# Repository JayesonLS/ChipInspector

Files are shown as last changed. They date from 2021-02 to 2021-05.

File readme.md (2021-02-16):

Circuits for Arbitrary Inspection/Operation of Integrated Circuits
==================================================================

ChipInspector24
---------------

Circuit that made use of the many 5v pins on a Teensy++. Never 
tested as the need came about for a 50 pin device.

ChipInspector40
---------------

Circuit using an inexpensive Arduino Pro Micro and many input
and output shift registers. Very incomplete.

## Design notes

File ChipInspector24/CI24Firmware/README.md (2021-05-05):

Chip Inspector 24 Firmware
==========================

The firmware is built and programmed with 
[Teensyduino](https://www.pjrc.com/teensy/td_download.html).

Teensyduino version 1.53
Arduino version 1.8.13

Operation
---------

To operate the Chip Inspector 24, connect the Teensy to 
computer, then run a serial terminal to communicate with
the board. The serial terminal in the Arduino environment
may be used. 

Chip Inspector 23 is controlled with the following commands
from the serial terminal.

**`logicdump <device pin count>`**

For example, `logicdump 20`. 

This command will attempt to apply every possible combination
of inputs to every non-power pin of the inserted device. Inputs 
are driven through a 10K resistor. For every combination of inputs,
the levels on the device pins are read back. Every combination 
attempted inputs and actual pin values are then output to the 
serial terminal.

Before the logic dump begins, the device is powered up and a
current test is applied. The test will be halted if excessive
current consumption is detected.

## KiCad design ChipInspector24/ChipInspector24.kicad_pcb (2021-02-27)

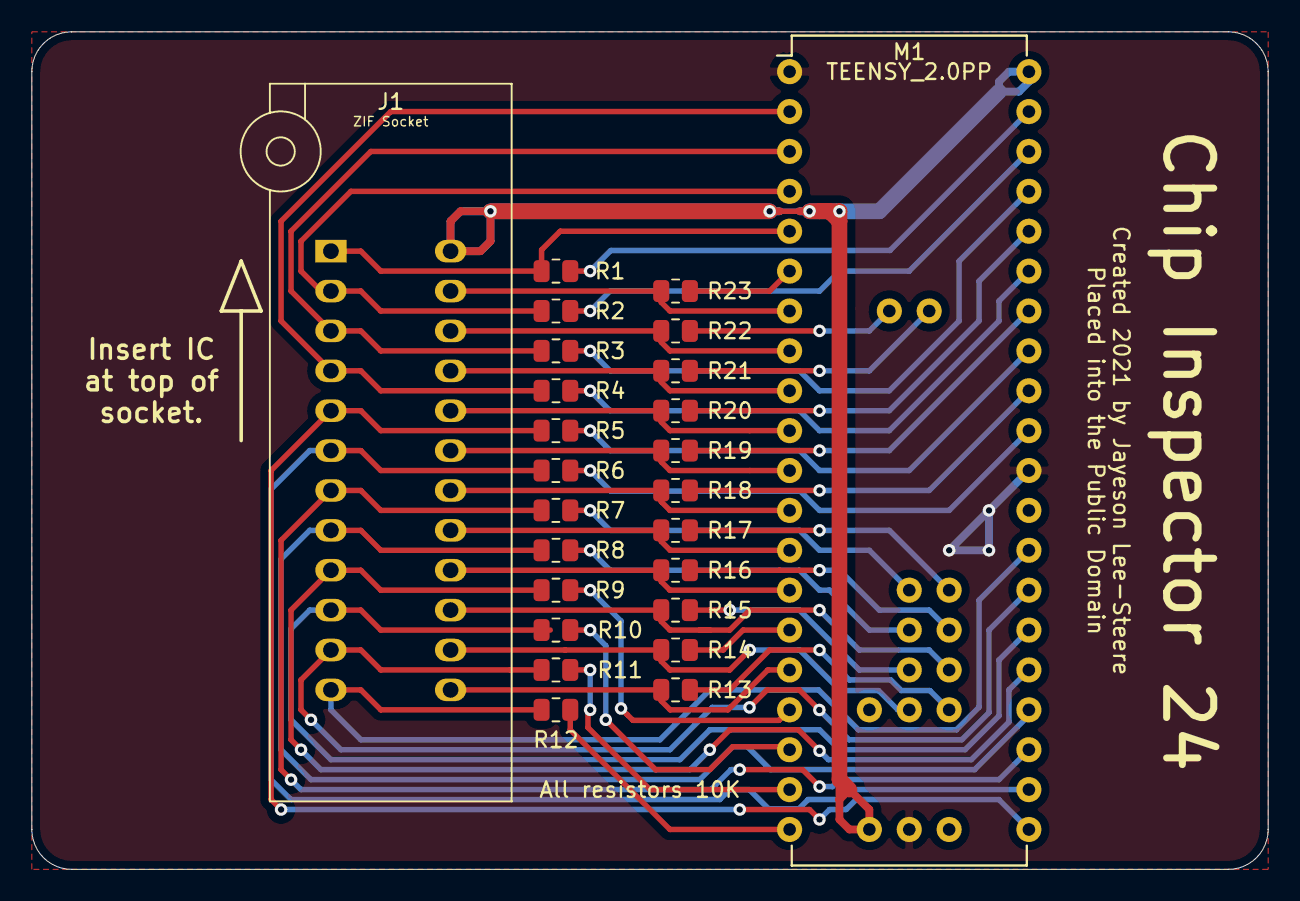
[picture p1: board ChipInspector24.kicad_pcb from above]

Board: 2 copper layers, 78.7 x 53.3 mm, 25 parts (0 on the bottom side), 48 nets.

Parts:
J1: ZIF Socket; DIP_Socket-24_W4.3_W5.08_W7.62_W10.16_W10.9_3M_224-5248-00-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
M1: TEENSY_2.0PP; Teensy_2.0PP
R1, R2, R3, R4, R5, R6, R7, R8, R9, R10, R11, R12, R13, R14, R15, R16, R17, R18, R19, R20, R21, R22, R23: 10K; R_0805_2012Metric

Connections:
GND: M1.1, M1.30, M1.42
P01: J1.1, M1.5, R1.1
P01R: M1.39, R1.2
P02: J1.2, M1.4, R2.1
P02R: M1.38, R2.2
P03: J1.3, M1.3, R3.1
P03R: M1.37, R3.2
P04: J1.4, M1.2, R4.1
P04R: M1.35, R4.2
P05: J1.5, M1.21, R5.1
P05R: M1.33, R5.2
P06: J1.6, M1.22, R6.1
P06R: M1.31, R6.2
P07: J1.7, M1.23, R7.1
P07R: M1.45, R7.2
P08: J1.8, M1.24, R8.1
P08R: M1.46, R8.2
P09: J1.9, M1.25, R9.1
P09R: M1.17, R9.2
P10: J1.10, M1.26, R10.1
P10R: M1.18, R10.2
P11: J1.11, M1.27, R11.1
P11R: M1.19, R11.2
P12: J1.12, M1.28, R12.1
P12R: M1.20, R12.2
P13: J1.13, M1.16, R13.1
P13R: M1.49, R13.2
P14: J1.14, M1.48, R14.1
P14R: M1.15, R14.2
P15: J1.15, M1.50, R15.1
P15R: M1.47, R15.2
P16: J1.16, M1.14, R16.1
P16R: M1.51, R16.2
P17: J1.17, M1.13, R17.1
P17R: M1.52, R17.2
P18: J1.18, M1.12, R18.1
P18R: M1.32, R18.2
P19: J1.19, M1.11, R19.1
P19R: M1.34, R19.2
P20: J1.20, M1.10, R20.1
P20R: M1.36, R20.2
P21: J1.21, M1.9, R21.1
P21R: M1.53, R21.2
P22: J1.22, M1.8, R22.1
P22R: M1.54, R22.2
P23: J1.23, M1.7, R23.1
P23R: M1.6, R23.2
VCC: J1.24, M1.40, M1.41

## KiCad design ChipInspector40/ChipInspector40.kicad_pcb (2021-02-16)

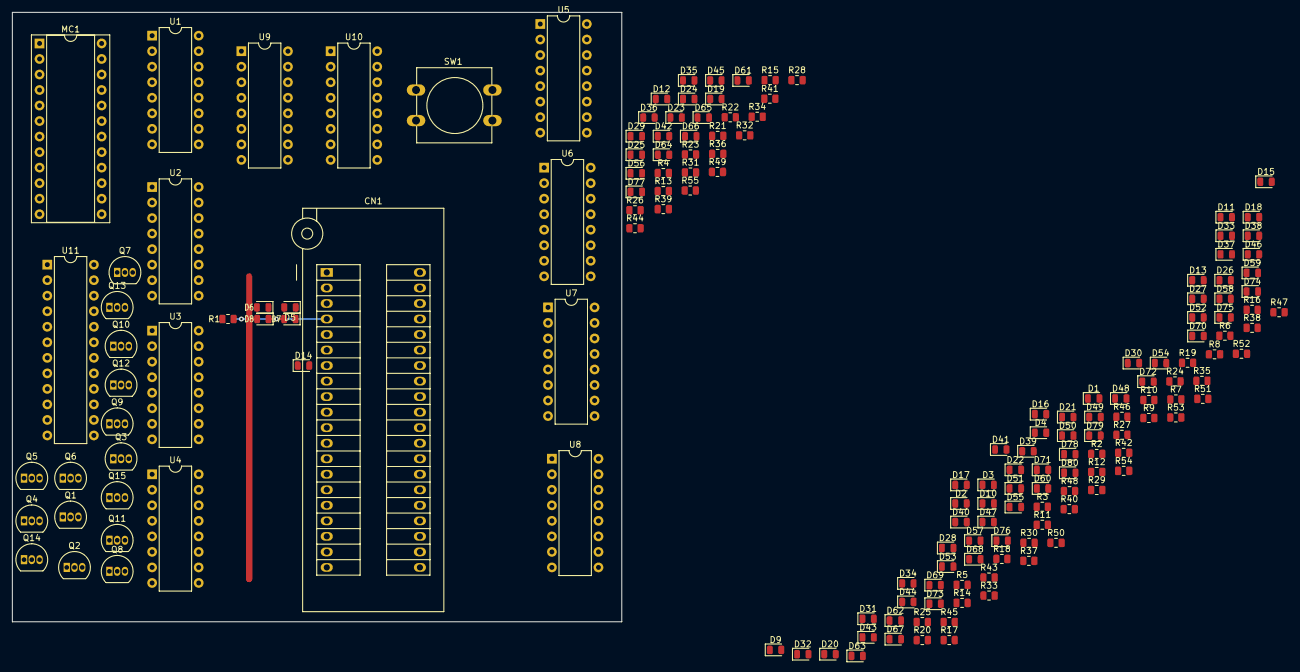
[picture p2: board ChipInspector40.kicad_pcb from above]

Board: 2 copper layers, 99.7 x 99.7 mm, 164 parts (0 on the bottom side), 120 nets.

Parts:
CN1: 40 Pin ZIF; 3M_Textool_240-1288-00-0602J_2x20_P2.54mm
D1, D2, D3, D4, D5, D6, D7, D8, D9, D10, D11, D12, D13, D14, D15, D16, D17, D18, D19, D20, D21, D22, D23, D24, D25, D26, D27, D28, D29, D30, D31, D32, D33, D34, D35, D36, D37, D38, D39, D40, D41, D42, D43, D44, D45, D46, D47, D48, D49, D50, D51, D52, D53, D54, D55, D56, D57, D58, D59, D60, D61, D62, D63, D64, D65, D66, D67, D68, D69, D70, D71, D72, D73, D74, D75, D76, D77, D78, D79, D80: 1N4148; D_0805_2012Metric
MC1: ARDUINO_PRO_MICRO; DIP-24_W10.16mm_Socket
Q1, Q2, Q3, Q4, Q5, Q6, Q7, Q8, Q9, Q10, Q11, Q12, Q13, Q14, Q15: PN2222A; TO-92_Inline
R1, R2, R3, R4, R5, R6, R7, R8, R9, R10, R11, R12, R13, R14, R15, R16, R17, R18, R19, R20, R21, R22, R23, R24, R25, R26, R27, R28, R29, R30, R31, R32, R33, R34, R35, R36, R37, R38, R39, R40: 10K; R_0805_2012Metric
R41, R42, R43, R44, R45, R46, R47, R48, R49, R50, R51, R52, R53, R54, R55: 1K; R_0805_2012Metric
SW1: Reset; SW_PUSH-12mm
U1, U2, U3, U4, U5: 74LS/HC165; DIP-16_W7.62mm
U6, U7, U8, U9, U10: 74LS/HC595; DIP-16_W7.62mm
U11: 74LS154; DIP-24_W7.62mm

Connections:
/PIN1: CN1.1, D1.2, D2.1, R1.2, U1.11
/PIN1_DRIVE: R1.1, U6.15
/PIN2: CN1.2, D3.2, D4.1, R2.2, U1.12
/PIN2_DRIVE: R2.1, U6.1
/PIN2_READ: Q1.3, Q2.3
/PIN3: CN1.3, D5.2, D6.1, R3.2, U1.13
/PIN3_DRIVE: R3.1, U6.2
/PIN4: CN1.4, D7.2, D8.1, R4.2, U1.14
/PIN4_DRIVE: R4.1, U6.3
/PIN5: CN1.5, D9.2, D10.1, R5.2, U1.3
/PIN5_DRIVE: R5.1, U6.4
/PIN6: CN1.6, D11.2, D12.1, R6.2, U1.4
/PIN6_DRIVE: R6.1, U6.5
/PIN7: CN1.7, D13.2, D14.1, R7.2, U1.5
/PIN7_DRIVE: R7.1, U6.6
/PIN8: CN1.8, D15.2, D16.1, R8.2, U1.6
/PIN8_DRIVE: R8.1, U6.7
/PIN9: CN1.9, D17.2, D18.1, R9.2, U2.11
/PIN9_DRIVE: R9.1, U7.15
/PIN10: CN1.10, D19.2, D20.1, R10.2, U2.12
/PIN10_DRIVE: R10.1, U7.1
/PIN11: CN1.11, D21.2, D22.1, R11.2, U2.13
/PIN11_DRIVE: R11.1, U7.2
/PIN12: CN1.12, D23.2, D24.1, R12.2, U2.14
/PIN12_DRIVE: R12.1, U7.3
/PIN13: CN1.13, D25.2, D26.1, R13.2, U2.3
/PIN13_DRIVE: R13.1, U7.4
/PIN14: CN1.14, D27.2, D28.1, R14.2, U2.4
/PIN14_DRIVE: R14.1, U7.5
/PIN15: CN1.15, D29.2, D30.1, R15.2, U2.5
/PIN15_DRIVE: R15.1, U7.6
/PIN16: CN1.16, D31.2, D32.1, R16.2, U2.6
/PIN16_DRIVE: R16.1, U7.7
/PIN17: CN1.17, D33.2, D34.1, R17.2, U3.11
/PIN17_DRIVE: R17.1, U8.15
/PIN18: CN1.18, D35.2, D36.1, R18.2, U3.12
/PIN18_DRIVE: R18.1, U8.1
/PIN19: CN1.19, D37.2, D38.1, R19.2, U3.13
/PIN19_DRIVE: R19.1, U8.2
/PIN20: CN1.20, D39.2, D40.1, R20.2, U3.14
/PIN20_DRIVE: R20.1, U8.3
/PIN21: CN1.21, D41.2, D42.1, R40.2, U3.3
/PIN21_DRIVE: R40.1, U8.4
/PIN22: CN1.22, D43.2, D44.1, R39.2, U3.4
/PIN22_DRIVE: R39.1, U8.5
/PIN23: CN1.23, D45.2, D46.1, R38.2, U3.5
/PIN23_DRIVE: R38.1, U8.6
/PIN24: CN1.24, D47.2, D48.1, R37.2, U3.6
/PIN24_DRIVE: R37.1, U8.7
/PIN25: CN1.25, D49.2, D50.1, R36.2, U4.11
/PIN25_DRIVE: R36.1, U9.15
/PIN26: CN1.26, D51.2, D52.1, R35.2, U4.12
/PIN26_DRIVE: R35.1, U9.1
/PIN27: CN1.27, D53.2, D54.1, R34.2, U4.13
/PIN27_DRIVE: R34.1, U9.2
/PIN28: CN1.28, D55.2, D56.1, R33.2, U4.14
/PIN28_DRIVE: R33.1, U9.3
/PIN29: CN1.29, D57.2, D58.1, R32.2, U4.3
/PIN29_DRIVE: R32.1, U9.4
/PIN30: CN1.30, D59.2, D60.1, R31.2, U4.4
/PIN30_DRIVE: R31.1, U9.5
/PIN31: CN1.31, D61.2, D62.1, R30.2, U4.5
/PIN31_DRIVE: R30.1, U9.6
/PIN32: CN1.32, D63.2, D64.1, R29.2, U4.6
/PIN32_DRIVE: R29.1, U9.7
/PIN33: CN1.33, D65.2, D66.1, R28.2, U5.11
/PIN33_DRIVE: R28.1, U10.15
/PIN34: CN1.34, D67.2, D68.1, R27.2, U5.12
/PIN34_DRIVE: R27.1, U10.1
/PIN35: CN1.35, D69.2, D70.1, R26.2, U5.13
/PIN35_DRIVE: R26.1, U10.2
/PIN36: CN1.36, D71.2, D72.1, R25.2, U5.14
/PIN36_DRIVE: R25.1, U10.3
/PIN37: CN1.37, D73.2, D74.1, R24.2, U5.3
/PIN37_DRIVE: R24.1, U10.4
/PIN38: CN1.38, D75.2, D76.1, R23.2, U5.4
/PIN38_DRIVE: R23.1, U10.5
/PIN39: CN1.39, D77.2, D78.1, R22.2, U5.5
/PIN39_DRIVE: R22.1, U10.6
/PIN40: CN1.40, D79.2, D80.1, R21.2, U5.6
/PIN40_DRIVE: R21.1, U10.7
GND: D2.2, D4.2, D6.2, D8.2, D10.2, D12.2, D14.2, D16.2, D18.2, D20.2, D22.2, D24.2, D26.2, D28.2, D30.2, D32.2, D34.2, D36.2, D38.2, D40.2, D42.2, D44.2, D46.2, D48.2, D50.2, D52.2, D54.2, D56.2, D58.2, D60.2, D62.2, D64.2, D66.2, D68.2, D70.2, D72.2, D74.2, D76.2, D78.2, D80.2, MC1.3, MC1.4, Q1.1, Q2.1, Q3.1, Q4.1, Q5.1, Q6.1, Q7.1, Q8.1, Q9.1, Q10.1, Q11.1, Q12.1, Q13.1, Q14.1, Q15.1, SW1.2, U1.8, U1.10, U1.15, U2.8, U2.15, U3.8, U3.15, U4.8, U4.15, U5.8, U5.15, U6.8, U7.8, U8.8, U9.8, U10.8, U11.12, U11.18, U11.19
unnamed: MC1.22, SW1.1
unnamed: Q1.2, R41.1
unnamed: Q2.2, R42.1
unnamed: Q3.2, R43.1
unnamed: Q4.2, R44.1
unnamed: Q5.2, R45.1
unnamed: Q6.2, R46.1
unnamed: Q7.2, R47.1
unnamed: Q8.2, R48.1
unnamed: Q9.2, R49.1
unnamed: Q10.2, R50.1
unnamed: Q11.2, R51.1
unnamed: Q12.2, R52.1
unnamed: Q13.2, R53.1
unnamed: Q14.2, R54.1
unnamed: Q15.2, R55.1
unnamed: R41.2, U11.2
unnamed: R42.2, U11.3
unnamed: R43.2, U11.4
unnamed: R44.2, U11.5
unnamed: R45.2, U11.6
unnamed: R46.2, U11.7
unnamed: R47.2, U11.8
unnamed: R48.2, U11.9
unnamed: R49.2, U11.10
unnamed: R50.2, U11.11
unnamed: R51.2, U11.13
unnamed: R52.2, U11.14
unnamed: R53.2, U11.15
unnamed: R54.2, U11.16
unnamed: R55.2, U11.17
unnamed: U1.1, U2.1, U3.1, U4.1, U5.1
unnamed: U1.2, U2.2, U3.2, U4.2, U5.2
unnamed: U1.9, U2.10
unnamed: U2.9, U3.10
unnamed: U3.9, U4.10
unnamed: U4.9, U5.10
VCC: D1.1, D3.1, D5.1, D7.1, D9.1, D11.1, D13.1, D15.1, D17.1, D19.1, D21.1, D23.1, D25.1, D27.1, D29.1, D31.1, D33.1, D35.1, D37.1, D39.1, D41.1, D43.1, D45.1, D47.1, D49.1, D51.1, D53.1, D55.1, D57.1, D59.1, D61.1, D63.1, D65.1, D67.1, D69.1, D71.1, D73.1, D75.1, D77.1, D79.1, MC1.21, U1.16, U2.16, U3.16, U4.16, U5.16, U6.16, U7.16, U8.16, U9.16, U10.16, U11.24

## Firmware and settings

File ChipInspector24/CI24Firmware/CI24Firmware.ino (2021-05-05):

/* 
Chip Inspector 24 Firmware
Copyright (C) 2021 Titanium Studios Pty. Ltd.

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
You should have received a copy of the GNU General Public License
along with this program.  If not, see <http://www.gnu.org/licenses/>.
*/

#include "LogicDump.h"
#include "PinControl.h"

const char* HELP_COMMAND = "help";
const char* LOGICDUMP_COMMAND = "logicdump";

const char* LOGICDUMP_SUPPORTED_PIN_COUNTS_TEXT = "10, 12, 14, 16, 18, 20, 22 or 24";

// the setup routine runs once when you press reset:
void setup()
{
  Serial.begin(9600); // USB is always 12 Mbit/sec

  DebugCheckSocketPins();
}

String ReadCommandString()
{
  String result;

  for (;;)
  {
    while (Serial.available())
    {
      int data = Serial.read();
      if (data == '\n')
      {
        return result;
      }
      else if (data >= 0)
      {
        result += (char)data;
      }
    }
  }
}

void ShowHelp()
{
    Serial.println("Supported commands:");
    Serial.println();

    Serial.print(HELP_COMMAND);
    Serial.println(" - Show this help");
    Serial.println();
    
    Serial.print(LOGICDUMP_COMMAND);
    Serial.println(" <pin count> - Dump I/O logic tables for device.");
    Serial.print("<pin count> is one of ");
    Serial.println(LOGICDUMP_SUPPORTED_PIN_COUNTS_TEXT);
    Serial.print("For example: ");
    Serial.print(LOGICDUMP_COMMAND);
    Serial.println(" 24");
    Serial.println();
}

bool IsSupportedDevicePinCount(int pinCount)
{
  return pinCount >= 10 && pinCount <= 24 && (pinCount % 0x01) == 0;
}

// the loop routine runs over and over again forever:
void loop()
{
  // Initialize Teensy.
  delay(100);  // Just in case a previous operation needs time to settle.
  //TODO: Set all pins to inputs.

  // Show welcome message. 
  Serial.print("Enter command string. Enter '");
  Serial.print(HELP_COMMAND);
  Serial.println("' for list of commands.");
  
  String commandString = ReadCommandString().trim().toLowerCase();
  if (commandString.length() > 0)
  {   
    Serial.print("Received command string: ");
    Serial.println(commandString);

    if (commandString == HELP_COMMAND)
    {
      ShowHelp();
    }
    else if (commandString.startsWith(LOGICDUMP_COMMAND))
    {
      int pinCount = 0;

      if (sscanf(commandString.c_str() + strlen(LOGICDUMP_COMMAND), "%d", &pinCount) != 1 ||
          !IsSupportedDevicePinCount(pinCount))
      {
        Serial.print("Please specify one of the supported pin counts: ");
        Serial.println(LOGICDUMP_SUPPORTED_PIN_COUNTS_TEXT);
      }
      else
      {
        LogicDump(pinCount);
      }
    }
    else
    {
        Serial.println("Unrecognised command.");
    }
  }
}

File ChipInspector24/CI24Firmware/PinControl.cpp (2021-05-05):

/* 
Chip Inspector 24 Firmware
Copyright (C) 2021 Titanium Studios Pty. Ltd.

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
You should have received a copy of the GNU General Public License
along with this program.  If not, see <http://www.gnu.org/licenses/>.
*/

#include <Arduino.h>
#include "PinControl.h"

#define MAX_PINS 24
#define MAX_IO_PINS 22

static uint8_t socketDirectPins[MAX_PINS] =
{
  2, // 1
  1, // 2
  0, // 3
  27, // 4
  45, // 5
  44, // 6
  43, // 7
  42, // 8
  41, // 9
  40, // 10
  39, // 11
  38, // 12
  13, // 13
  35, // 14
  30, // 15
  11, // 16
  10, // 17
  9, // 18
  8, // 19
  7, // 20
  6, // 21
  5, // 22
  4, // 23
  (uint8_t)-1  // 24
};

static uint8_t socketResistorPins[MAX_PINS] =
{
  26, // 1
  37, // 2
  24, // 3
  22, // 4
  20, // 5
  18, // 6
  32, // 7
  33, // 8
  14, // 9
  15, // 10
  16, // 11
  17, // 12
  31, // 13
  12, // 14
  34, // 15
  29, // 16
  28, // 17
  19, // 18
  21, // 19
  23, // 20
  25, // 21
  36, // 22
  3, // 23
  (uint8_t)-1  // 24
};

static uint8_t socketAnalogDirectPins[MAX_PINS] =
{
  (uint8_t)-1, // 1
  (uint8_t)-1, // 2
  (uint8_t)-1, // 3
  (uint8_t)-1, // 4
  A7, // 5
  A6, // 6
  A5, // 7
  A4, // 8
  A3, // 9
  A2, // 10
  A1, // 11
  A0, // 12
  (uint8_t)-1, // 13
  (uint8_t)-1, // 14
  (uint8_t)-1, // 15
  (uint8_t)-1, // 16
  (uint8_t)-1, // 17
  (uint8_t)-1, // 18
  (uint8_t)-1, // 19
  (uint8_t)-1, // 20
  (uint8_t)-1, // 21
  (uint8_t)-1, // 22
  (uint8_t)-1, // 23
  (uint8_t)-1  // 24
};

void DebugCheckSocketPins()
{
  for (int i = 0; i < MAX_PINS; i++)
  {
    uint8_t directPin = socketDirectPins[i];
    uint8_t resistorPin = socketResistorPins[i];

    for (int j = 0; j < MAX_PINS; j++)
    {
      if (directPin != (uint8_t)-1)
      {
        if (directPin == socketDirectPins[j] && j != i)
        {
          Serial.println(String("!!!! ERROR !!!!: directPin[") + i + "] same as directPin[" + j + "].");
        }
        if (directPin == socketResistorPins[j])
        {
          Serial.println(String("!!!! ERROR !!!!: directPin[") + i + "] same as resistorPin[" + j + "].");
        }
      }
      if (resistorPin != (uint8_t)-1)
      {
        if (resistorPin == socketDirectPins[j])
        {
          Serial.println(String("!!!! ERROR !!!!: resistorPin[") + i + "] same as directPin[" + j + "].");
        }
        if (resistorPin == socketResistorPins[j] && j != i)
        {
          Serial.println(String("!!!! ERROR !!!!: resistorPin[") + i + "] same as resistorPin[" + j + "].");
        }
      }
    }
  }
}

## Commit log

2021-02-16 Add ChipInspector24.
    [ChipInspector24.kicad_pcb, ChipInspector24.sch]
2021-02-16 Add ChipInspector40.
    [ChipInspector40.kicad_pcb, ChipInspector40.sch]
2021-02-27 Commit latest PCB edits and gerber export.
    [ChipInspector24-B_Cu.gbr, ChipInspector24-B_Mask.gbr, ChipInspector24-B_SilkS.gbr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]
2021-05-05 Add socket pin mappings for CI24 Firmware.

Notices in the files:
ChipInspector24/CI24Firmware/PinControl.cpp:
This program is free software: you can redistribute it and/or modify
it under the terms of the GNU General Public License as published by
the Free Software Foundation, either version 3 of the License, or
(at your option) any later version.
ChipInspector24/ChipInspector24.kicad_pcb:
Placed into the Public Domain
